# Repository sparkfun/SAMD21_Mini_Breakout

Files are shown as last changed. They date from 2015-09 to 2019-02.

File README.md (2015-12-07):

SparkFun SAMD21 Mini Breakout
========================================

SparkFun SAMD21 Mini Breakout

[*SparkFun SAMD21 Mini Breakout (DEV-13664)*](https://www.sparkfun.com/products/13664)

The SAMD21 Mini Breakout is a [Pro Mini](https://www.sparkfun.com/products/11114)-sized breakout for the Atmel [ATSAMD21G18](http://www.atmel.com/devices/ATSAMD21G18.aspx), a 32-bit ARM Cortex-M0+ processor with 256KB flash, 32KB SRAM, and an operating speed of up to 48MHz. The SAMD21 is compatible with the Arduino IDE, and libraries for the Arduino Zero.

Repository Contents
-------------------

* **/Documentation** - Data sheets, additional product information
* **/Firmware** - SAMD21 Arduino Bootloader
* **/Hardware** - Eagle design files (.brd, .sch)
* **/Production** - Production panel files (.brd)

Documentation
--------------
* **[Hookup Guide](https://learn.sparkfun.com/tutorials/samd21-minidev-breakout-hookup-guide/resources--going-further)** - Basic hookup guide for the SAMD21 Mini Breakout.

Product Versions
----------------
* [DEV-13664](https://www.sparkfun.com/products/13664) - Initial product release - v10.
* [DEV-13672](https://www.sparkfun.com/products/13672) - The SparkFun SAMD21 _Dev_ Breakout -- a similar, Arduino-shaped version of this board.

Version History
---------------
* [v1.0](https://github.com/sparkfun/SAMD21G_Mini_Breakout/tree/v10) - Initial release 

License Information
-------------------

This product is _**open source**_! 

Please review the LICENSE.md file for license information. 

If you have any questions or concerns on licensing, please contact techsupport@sparkfun.com.

Distributed as-is; no warranty is given.

- Your friends at SparkFun.

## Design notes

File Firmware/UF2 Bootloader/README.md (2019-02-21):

UF2 Bootloader for the SAMD21 Mini Breakout
==========================================
**Current Version**: UF2 Bootloader v3.2.2-1-gdec2fb7-dirty SFHWRO
**Updated**: 2/20/2019

What is UF2? It's probably best to read the documents [HERE](https://makecode.com/blog/one-chip-to-flash-them-all). The TLDR however, is that it's a bootloader that turns your micro-controller 
into a flash drive. The example bootloader provided here was created 2/20/2019
and further support is not guaranteed. However you can learn a bit about _how_
to build your own bootloader at Microsoft's [repo](https://github.com/Microsoft/uf2).
The hardest part will be ensuring that you have all the necessary build dependencies.

To update your SAMD21 Mini with the bootloader is simple. If you already have a
bootloader on it, i.e. you can see it populate in Arduino and/or Device
Manager, then all you have to do is open the "Update-Bootloader.ino" sketch and
upload it. Afterwards, you should see the SAMD21 pop up as a **SPARKFUN** drive. 
I have also included an "update" binary file for those that want to use some
GUI or command line interface instead, as well as _just_ the bootloader for
those that don't already have a bootloader installed on their micro-controller.

Circuit Python 
------------------
**Current Version**: Adafruit CircuitPython 4.0.0-beta.1-46-g3d0757102  
**Updated**: 2/20/2019

Circuit Python is Adafruit's version of Micro Python. You can read general
information about it [HERE](https://learn.adafruit.com/welcome-to-circuitpython).
They also have some documentation on how to build a version of Circuit Python
on their website [here](https://learn.adafruit.com/building-circuitpython/build-circuitpython). 
I have included a build of it under the Circuit Python folder. Assuming that
you have uploaded the UF2 bootloader above, than all you need to do is drag and
drop the UF2 file in the Circuit Python folder into your **SPARKFUN** drive and 
you're good to go! The Sparkfun drive will momentarily disappear and a **CIRCUITPY** 
drive will take its place.

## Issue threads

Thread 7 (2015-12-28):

PWM D13 led

wifixcort, 2015-12-28:
Hi, I'm currently testing this Mini board and I maybe find a strange behavior.
With your example in this page https://learn.sparkfun.com/tutorials/samd21-minidev-breakout-hookup-guide/setting-up-arduino.

When I upload the sketch  the led 13 does not fade. If I change the board from Mini to Dev board all good.

jimblom, 2016-01-21:
This is an unfortunate side effect of equipping pins 10-13 on the Mini with SPI support (compare the [Mini's pin 13 declaration](https://github.com/sparkfun/Arduino_Boards/blob/master/sparkfun/samd/variants/SparkFun_SAMD_Mini/variant.cpp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) to the [Dev/Zero's](https://github.com/sparkfun/Arduino_Boards/blob/master/sparkfun/samd/variants/arduino_zero/variant.cpp#L137)). The pin's peripheral is, at least initially, muxed to SERCOM instead of a timer.

The [pinPeripheral function](https://github.com/sparkfun/Arduino_Boards/blob/master/sparkfun/samd/cores/arduino/wiring_private.c#L22) can be used to change a pin's mux, but it's not publicly available to the Arduino sketch. Adding **`#include "wiring_private.h"`** to the top of the sketch, and throwing **`pinPeripheral(13, PIO_TIMER);`** at the start of `setup()` isn't pretty, but it works.

Thanks for the letting us know about this. I'll make a note in the tutorial.

drewfish, 2016-01-21:
Yeah, I desoldered the LED 13 from my Mini so that SPI traffic wouldn't light it up (and eat battery power).

ianccole, 2020-07-16:
I think it's not enough to re-program the port mux  - you also need to modify g_APinDescription for the specified pin.

analogWrite() uses g_APinDescription to control it's action

ianccole, 2020-07-16:
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

I think it's not enough to re-program the port mux - you also need to modify g_APinDescription for the specified pin.

analogWrite() uses g_APinDescription to control it's action

Closed 2016-01-21.

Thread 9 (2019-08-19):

Crystal 32.7khrz? specficcations 48MHz  ?

ThomasLengeling, 2019-08-19:
The schematics say that the board is using a 32.7hrz and the specifications mention that the board runs at 48Mhrz. Does the board runs with the external clock or the internal?

Thank you for your help.

spacenate, 2023-08-11:
An external 32.768 kHz crystal oscillator allows for higher accuracy (and is required for some peripherals, i.e USB in host mode).

See this excellent blog post for more details: https://blog.thea.codes/understanding-the-sam-d21-clocks/

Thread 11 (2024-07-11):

PWM D13 led, take 2

abetis, 2024-07-11:
Hi.
Take 2 for the issue #7 .

Is there a solution to use the pin13 LED on the SparkFun SAMD21 Mini board as a PWM output?
Unfortunately `pinPeripheral(13, PIO_TIMER);` doesn't help.

Looks like the `g_APinDescription` have that line cofigured as PWM capable:
```
// 13 (LED)
  { PORTA, 17, PIO_SERCOM, (PIN_ATTR_DIGITAL|PIN_ATTR_PWM), No_ADC_Channel, PWM2_CH1, NOT_ON_TIMER, EXTERNAL_INT_1 }, // TCC2/WO[1]
```

But analogWrite on that pin do not light the LED.
And it doesn't default to digitalWrite either, so I guess there is something related to timers that should toggle the pin, but can't figure out what exactly should be done to make it work.

I use Sercom2 for I2C and want to use the build-in led on pin13 as a status indication with breathing LED.

Anyone managed to make that work?

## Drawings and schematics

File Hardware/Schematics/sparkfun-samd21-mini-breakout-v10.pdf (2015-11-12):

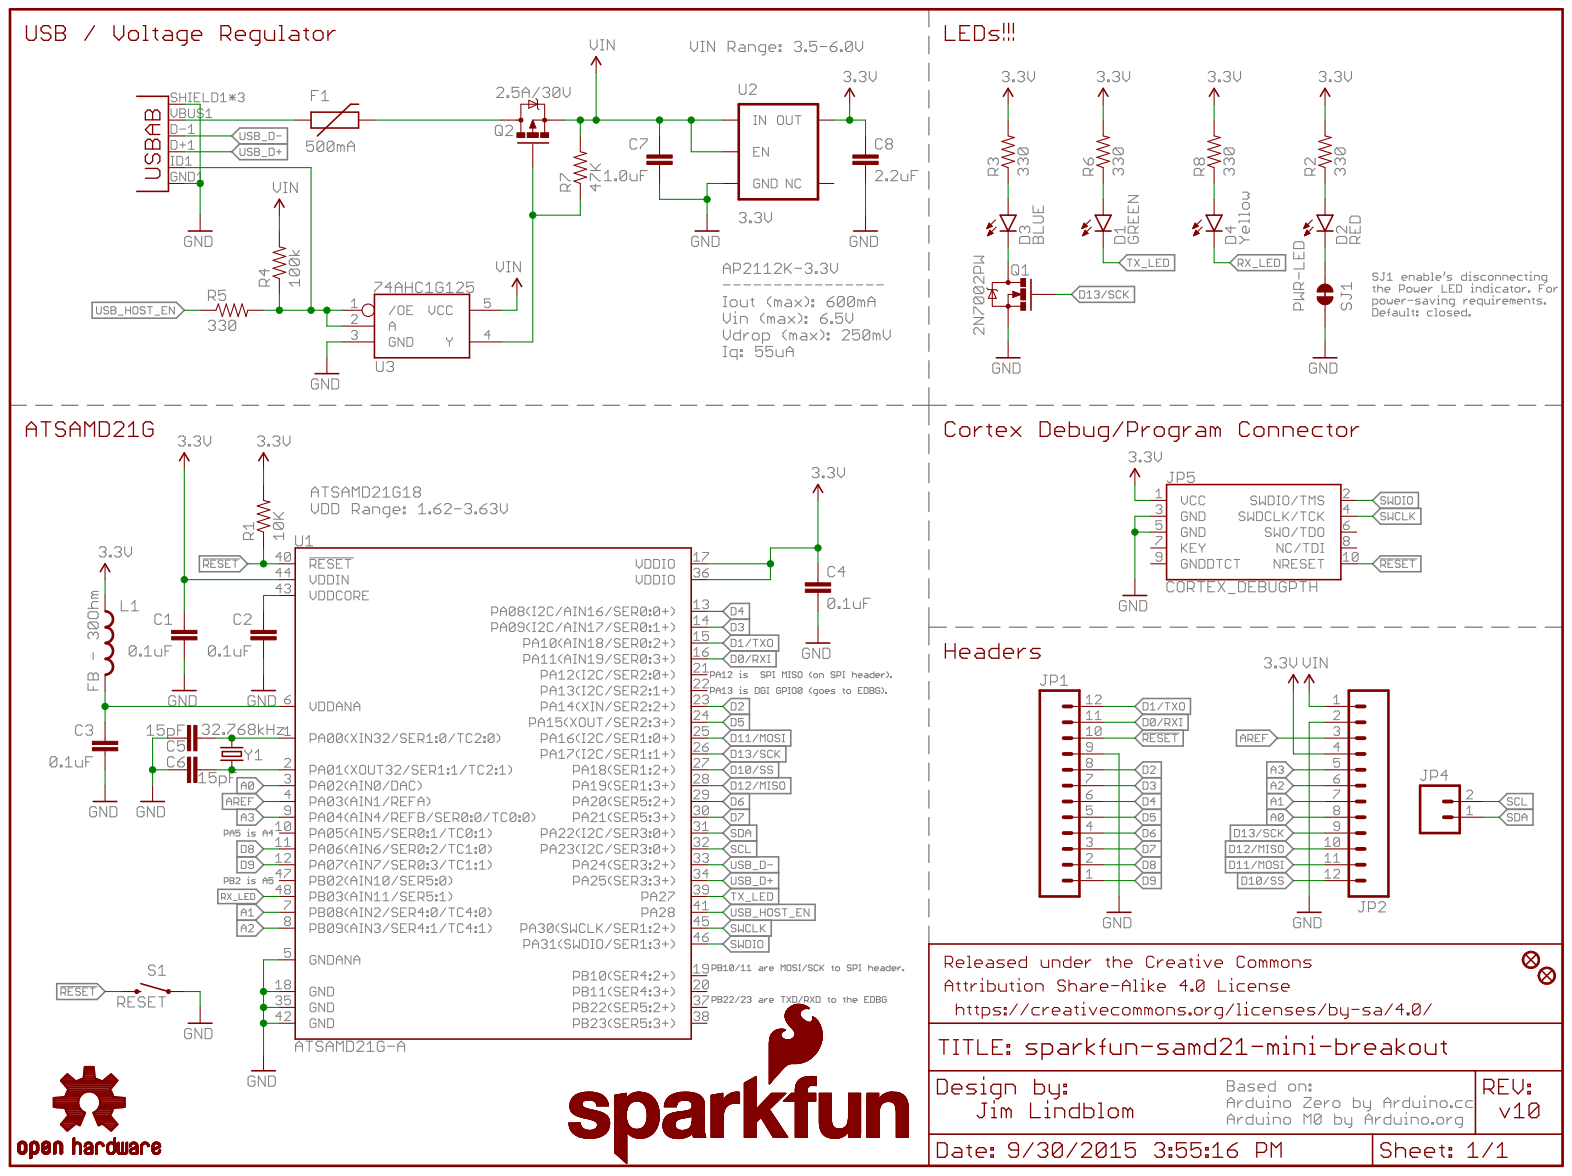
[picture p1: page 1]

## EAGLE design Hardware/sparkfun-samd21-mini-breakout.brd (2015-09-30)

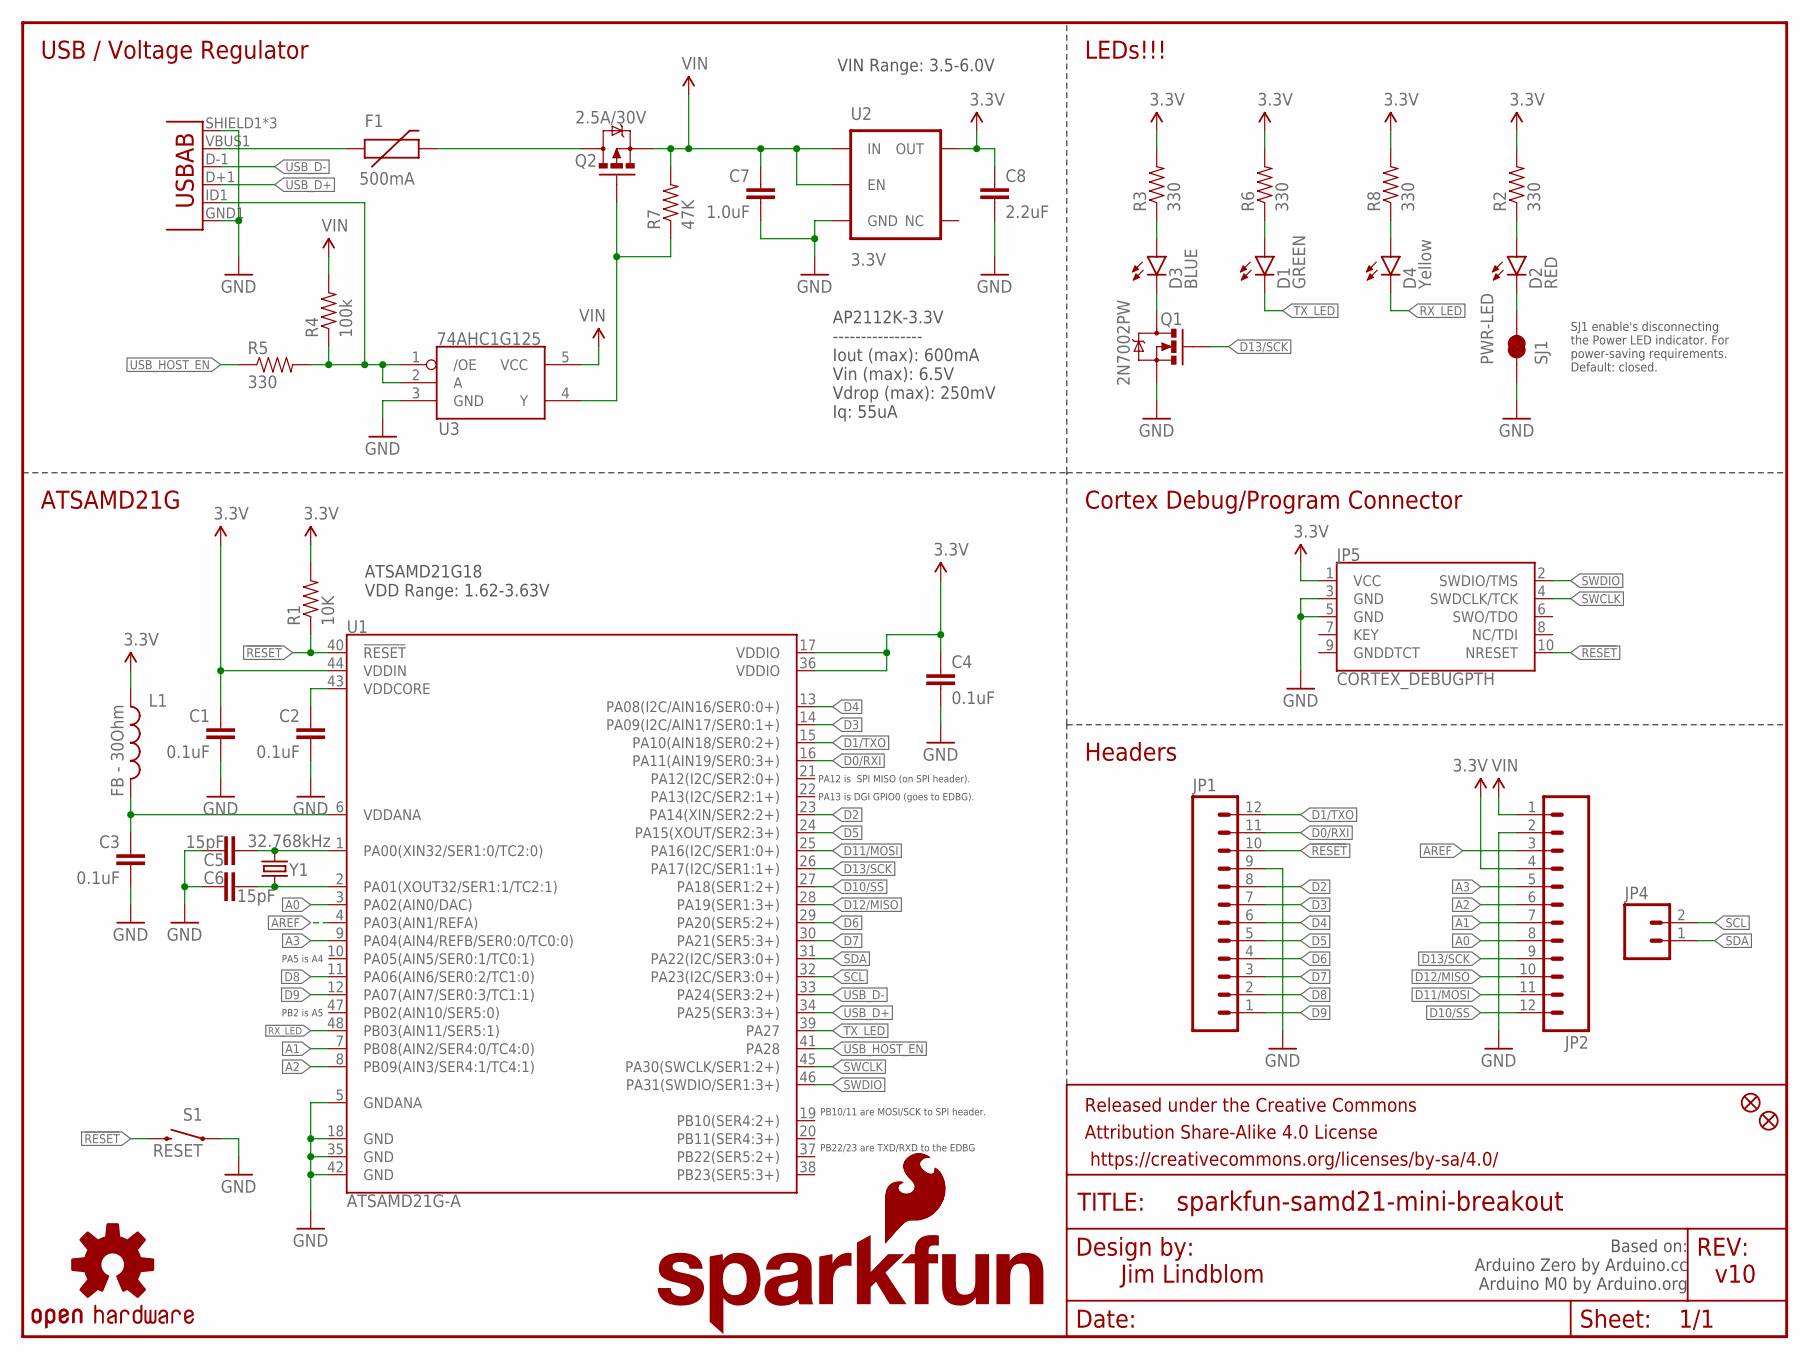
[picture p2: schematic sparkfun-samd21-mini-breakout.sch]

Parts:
C1, C2, C3, C4: 0.1uF; 0402-CAP
C5, C6: 15pF; 0402-CAP
C7: 1.0uF; 0805-CAP
C8: 2.2uF; 0603-CAP
D1: GREEN; LED-0603
D2: RED; LED-0603
D3: BLUE; LED-0603
D4: Yellow; LED-0603
F1: 500mA; PTC-1206
FID1, FID2: FIDUCIAL1X2; FIDUCIAL-1X2
FRAME1: FRAME-LETTER; CREATIVE_COMMONS
JP1, JP2: M12NO_SILK; 1X12_NO_SILK
JP3: USB-ABCONN-11794; USB-AB-MICRO-SMD_V03
JP4: M021X02_NO_SILK; 1X02_NO_SILK
JP5: CORTEX_DEBUGPTH; 2X5-PTH-1.27MM
L1: FB - 30Ohm; 0603
LOGO1: SFE_LOGO_FLAME.1_INCH; SFE_LOGO_FLAME_.1
LOGO2: OSHW-LOGOS; OSHW-LOGO-S
LOGO3: SFE_LOGO_NAME_FLAME.1_INCH; SFE_LOGO_NAME_FLAME_.1
Q1: 2N7002PW; SOT323
Q2: 2.5A/30V; SOT23-3
R1: 10K; 0603-RES
R2, R3, R5, R6, R8: 330; 0603-RES
R4: 100k; 0603-RES
R7: 47K; 0603-RES
S1: RESET; TACTILE_SWITCH_SMD_4.6X2.8MM
SJ1: PWR-LED; PAD-JUMPER-2-NC_BY_TRACE_NO_SILK
U1: ATSAMD21G-A; TQFP-48
U2: 3.3V; SOT23-5
U3: 74AHC1G125; SOT23-5
Y1: 32.768kHz; CRYSTAL-SMD-3.2X1.5MM

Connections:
3.3V: C1.1, C4.1, C8.1, JP2.4, JP5.1 (VCC), L1.1, R1.2, R2.2, R3.2, R6.2, R8.2, U1.17 (VDDIO), U1.36 (VDDIO), U1.44 (VDDIN), U2.5 (OUT)
!RESET: JP1.10, JP5.10 (NRESET), R1.1, S1.3 (2), S1.4 (2), U1.40 (!RESET!)
A0: JP2.8, U1.3 (PA02(AIN0/DAC))
A1: JP2.7, U1.7 (PB08(AIN2/SER4:0/TC4:0))
A2: JP2.6, U1.8 (PB09(AIN3/SER4:1/TC4:1))
A3: JP2.5, U1.9 (PA04(AIN4/REFB/SER0:0/TC0:0))
AREF: JP2.3, U1.4 (PA03(AIN1/REFA))
D0/RXI: JP1.11, U1.16 (PA11(AIN19/SER0:3+))
D1/TXO: JP1.12, U1.15 (PA10(AIN18/SER0:2+))
D2: JP1.8, U1.23 (PA14(XIN/SER2:2+))
D3: JP1.7, U1.14 (PA09(I2C/AIN17/SER0:1+))
D4: JP1.6, U1.13 (PA08(I2C/AIN16/SER0:0+))
D5: JP1.5, U1.24 (PA15(XOUT/SER2:3+))
D6: JP1.4, U1.29 (PA20(SER5:2+))
D7: JP1.3, U1.30 (PA21(SER5:3+))
D8: JP1.2, U1.11 (PA06(AIN6/SER0:2/TC1:0))
D9: JP1.1, U1.12 (PA07(AIN7/SER0:3/TC1:1))
D10/SS: JP2.12, U1.27 (PA18(SER1:2+))
D11/MOSI: JP2.11, U1.25 (PA16(I2C/SER1:0+))
D12/MISO: JP2.10, U1.28 (PA19(SER1:3+))
D13/SCK: JP2.9, Q1.1 (G), U1.26 (PA17(I2C/SER1:1+))
GND: C1.2, C2.2, C3.2, C4.2, C5.1, C6.2, C7.2, C8.2, JP1.9, JP2.2, JP3.GND1 (GND), JP3.SHIELD1 (SHIELD), JP3.SHIELD2 (SHIELD), JP3.SHIELD3 (SHIELD), JP5.3 (GND), JP5.5 (GND), Q1.2 (S), S1.1, S1.2 (1), SJ1.1, U1.5 (GNDANA), U1.18 (GND), U1.35 (GND), U1.42 (GND), U2.2 (GND), U3.3 (GND)
unnamed: F1.1, JP3.VBUS1 (VBUS)
unnamed: C5.2, U1.1 (PA00(XIN32/SER1:0/TC2:0)), Y1.P$2 (2)
unnamed: D3.C, Q1.3 (D)
unnamed: C6.1, U1.2 (PA01(XOUT32/SER1:1/TC2:1)), Y1.P$1 (1)
unnamed: D2.A, R2.1
unnamed: D3.A, R3.1
unnamed: F1.2, Q2.3 (D)
unnamed: JP3.ID1 (USBID), R4.1, R5.2, U3.1 (/OE), U3.2 (A)
unnamed: Q2.1 (G), R7.1, U3.4 (Y)
unnamed: D1.A, R6.1
unnamed: D4.A, R8.1
unnamed: D2.C, SJ1.2
RX_LED: D4.C, U1.48 (PB03(AIN11/SER5:1))
SCL: JP4.2, U1.32 (PA23(I2C/SER3:0+))
SDA: JP4.1, U1.31 (PA22(I2C/SER3:0+))
SWCLK: JP5.4 (SWDCLK/TCK), U1.45 (PA30(SWCLK/SER1:2+))
SWDIO: JP5.2 (SWDIO/TMS), U1.46 (PA31(SWDIO/SER1:3+))
TX_LED: D1.C, U1.39 (PA27)
USB_D+: JP3.D+1 (D+), U1.34 (PA25(SER3:3+))
USB_D-: JP3.D-1 (D-), U1.33 (PA24(SER3:2+))
USB_HOST_EN: R5.1, U1.41 (PA28)
VDDANA: C3.1, L1.2, U1.6 (VDDANA)
VDDCORE: C2.1, U1.43 (VDDCORE)
VIN: C7.1, JP2.1, Q2.2 (S), R4.2, R7.2, U2.1 (IN), U2.3 (EN), U3.5 (VCC)

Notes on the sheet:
PB22/23 are TXD/RXD to the EDBG
PB10/11 are MOSI/SCK to SPI header.
PA12 is SPI MISO (on SPI header).
PA13 is DGI GPIO0 (goes to EDBG).
PA5 is A4
PB2 is A5
USB / Voltage Regulator
LEDs!!!
Cortex Debug/Program Connector
Headers
ATSAMD21G
Jim Lindblom
v10
ATSAMD21G18 VDD Range: 1.62-3.63V
SJ1 enable's disconnecting the Power LED indicator. For power-saving requirements. Default: closed.
VIN Range: 3.5-6.0V
Based on: Arduino Zero by Arduino.cc Arduino M0 by Arduino.org
AP2112K-3.3V ---------------- Iout (max): 600mA Vin (max): 6.5V Vdrop (max): 250mV Iq: 55uA

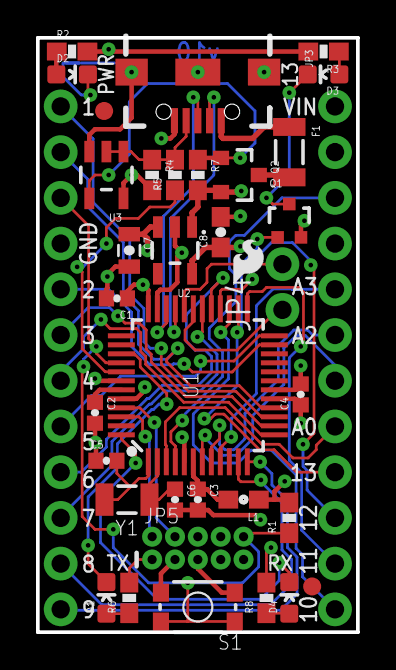
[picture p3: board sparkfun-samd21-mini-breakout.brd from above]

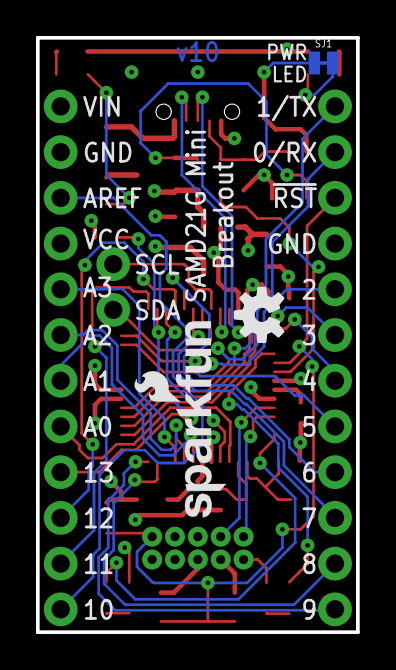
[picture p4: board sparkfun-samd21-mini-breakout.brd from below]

Board: 4 copper layers, 17.8 x 33.0 mm, 41 parts (3 on the bottom side), 46 nets.

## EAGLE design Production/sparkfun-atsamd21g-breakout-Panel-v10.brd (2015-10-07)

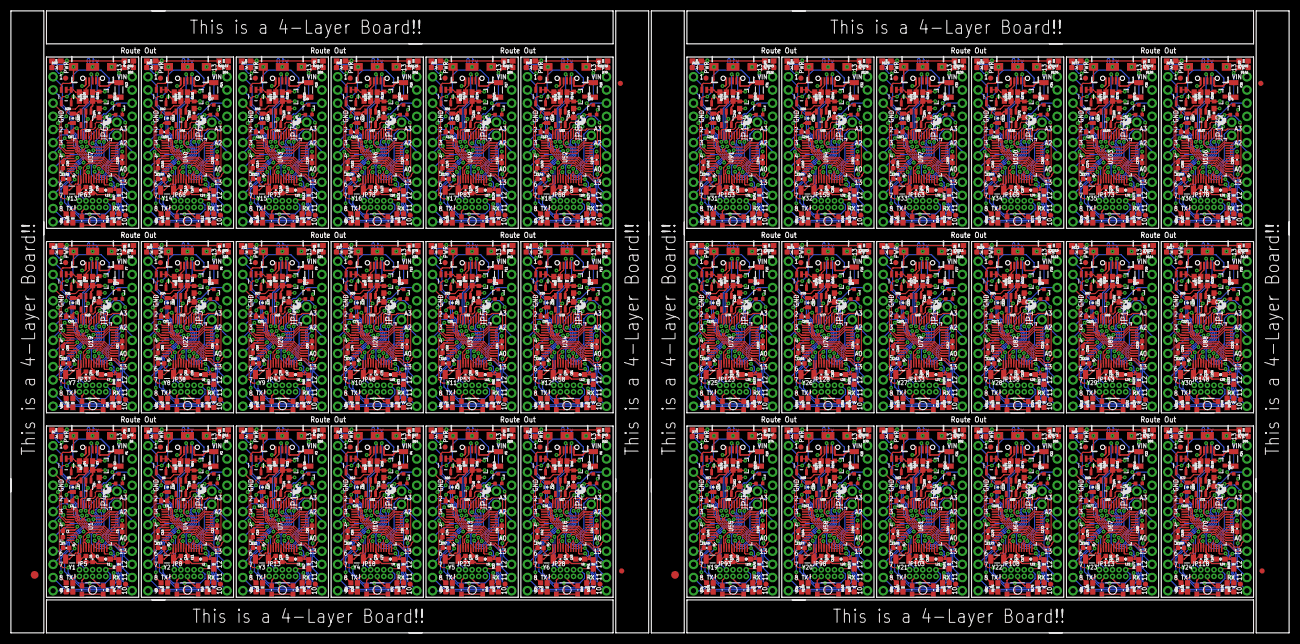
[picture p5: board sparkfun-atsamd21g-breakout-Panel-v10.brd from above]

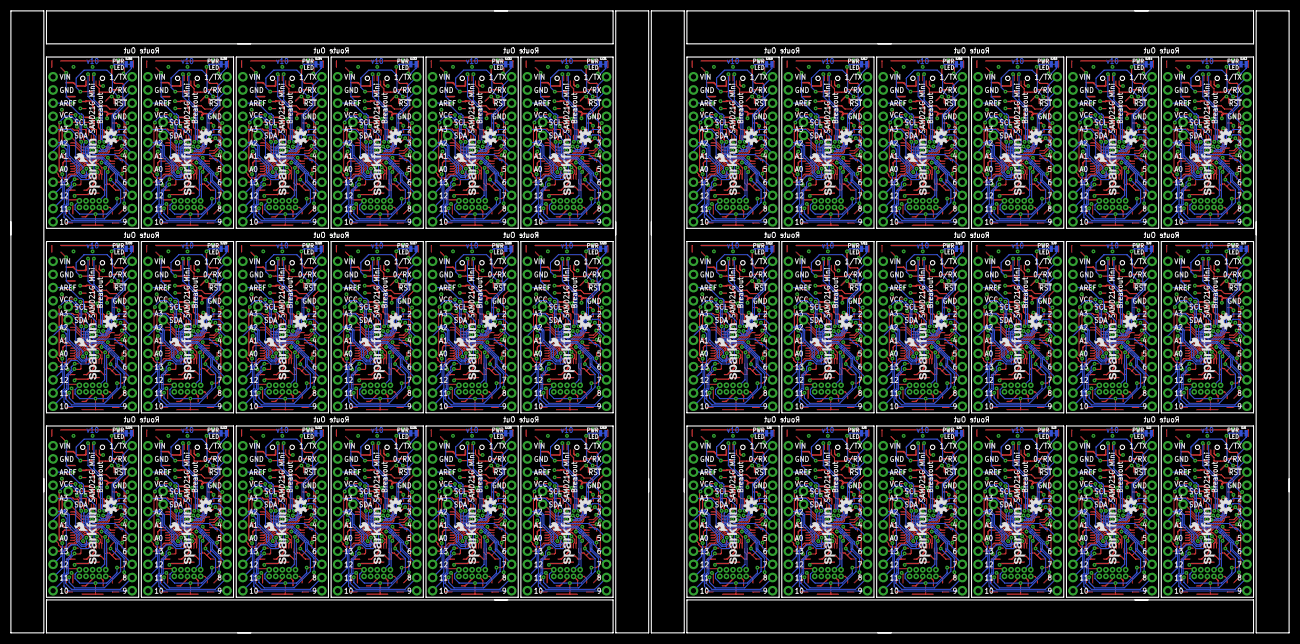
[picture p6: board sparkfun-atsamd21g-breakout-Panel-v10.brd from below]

Board: 4 copper layers, 246.4 x 119.9 mm, 1446 parts (108 on the bottom side), 1656 nets.

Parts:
C1, C2, C3, C4, C9, C10, C11, C12, C17, C18, C19, C20, C25, C26, C27, C28, C33, C34, C35, C36, C41, C42, C43, C44, C49, C50, C51, C52, C57, C58, C59, C60, C65, C66, C67, C68, C73, C74, C75, C76, C81, C82, C83, C84, C89, C90, C91, C92, C97, C98, C99, C100, C105, C106, C107, C108, C113, C114, C115, C116, C121, C122, C123, C124, C129, C130, C131, C132, C137, C138, C139, C140, C145, C146, C147, C148, C153, C154, C155, C156, C161, C162, C163, C164, C169, C170, C171, C172, C177, C178, C179, C180, C185, C186, C187, C188, C193, C194, C195, C196, C201, C202, C203, C204, C209, C210, C211, C212, C217, C218, C219, C220, C225, C226, C227, C228, C233, C234, C235, C236, C241, C242, C243, C244, C249, C250, C251, C252, C257, C258, C259, C260, C265, C266, C267, C268, C273, C274, C275, C276, C281, C282, C283, C284: 0.1uF; 0402-CAP
C5, C6, C13, C14, C21, C22, C29, C30, C37, C38, C45, C46, C53, C54, C61, C62, C69, C70, C77, C78, C85, C86, C93, C94, C101, C102, C109, C110, C117, C118, C125, C126, C133, C134, C141, C142, C149, C150, C157, C158, C165, C166, C173, C174, C181, C182, C189, C190, C197, C198, C205, C206, C213, C214, C221, C222, C229, C230, C237, C238, C245, C246, C253, C254, C261, C262, C269, C270, C277, C278, C285, C286: 15pF; 0402-CAP
C7, C15, C23, C31, C39, C47, C55, C63, C71, C79, C87, C95, C103, C111, C119, C127, C135, C143, C151, C159, C167, C175, C183, C191, C199, C207, C215, C223, C231, C239, C247, C255, C263, C271, C279, C287: 1.0uF; 0805-CAP
C8, C16, C24, C32, C40, C48, C56, C64, C72, C80, C88, C96, C104, C112, C120, C128, C136, C144, C152, C160, C168, C176, C184, C192, C200, C208, C216, C224, C232, C240, C248, C256, C264, C272, C280, C288: 2.2uF; 0603-CAP
D1, D7, D11, D15, D19, D23, D27, D31, D35, D39, D43, D47, D51, D55, D59, D63, D67, D71, D75, D79, D83, D87, D91, D95, D99, D103, D107, D111, D115, D119, D123, D127, D131, D135, D139, D143: GREEN; LED-0603
D2, D5, D9, D13, D17, D21, D25, D29, D33, D37, D41, D45, D49, D53, D57, D61, D65, D69, D73, D77, D81, D85, D89, D93, D97, D101, D105, D109, D113, D117, D121, D125, D129, D133, D137, D141: RED; LED-0603
D3, D6, D10, D14, D18, D22, D26, D30, D34, D38, D42, D46, D50, D54, D58, D62, D66, D70, D74, D78, D82, D86, D90, D94, D98, D102, D106, D110, D114, D118, D122, D126, D130, D134, D138, D142: BLUE; LED-0603
D4, D8, D12, D16, D20, D24, D28, D32, D36, D40, D44, D48, D52, D56, D60, D64, D68, D72, D76, D80, D84, D88, D92, D96, D100, D104, D108, D112, D116, D120, D124, D128, D132, D136, D140, D144: Yellow; LED-0603
E$1, E$4: FIDUCIAL-1.5X3
E$2, E$3, E$5, E$6: FIDUCIAL-1X2
F1, F2, F3, F4, F5, F6, F7, F8, F9, F10, F11, F12, F13, F14, F15, F16, F17, F18, F19, F20, F21, F22, F23, F24, F25, F26, F27, F28, F29, F30, F31, F32, F33, F34, F35, F36: 500mA; PTC-1206
FID1, FID2, FID3, FID4, FID5, FID6, FID7, FID8, FID9, FID10, FID11, FID12, FID13, FID14, FID15, FID16, FID17, FID18, FID19, FID20, FID21, FID22, FID23, FID24, FID25, FID26, FID27, FID28, FID29, FID30, FID31, FID32, FID33, FID34, FID35, FID36, FID37, FID38, FID39, FID40, FID41, FID42, FID43, FID44, FID45, FID46, FID47, FID48, FID49, FID50, FID51, FID52, FID53, FID54, FID55, FID56, FID57, FID58, FID59, FID60, FID61, FID62, FID63, FID64, FID65, FID66, FID67, FID68, FID69, FID70, FID71, FID72: FIDUCIAL1X2; FIDUCIAL-1X2
JP1, JP2, JP6, JP7, JP11, JP12, JP16, JP17, JP21, JP22, JP26, JP27, JP31, JP32, JP36, JP37, JP41, JP42, JP46, JP47, JP51, JP52, JP56, JP57, JP61, JP62, JP66, JP67, JP71, JP72, JP76, JP77, JP81, JP82, JP86, JP87, JP91, JP92, JP96, JP97, JP101, JP102, JP106, JP107, JP111, JP112, JP116, JP117, JP121, JP122, JP126, JP127, JP131, JP132, JP136, JP137, JP141, JP142, JP146, JP147, JP151, JP152, JP156, JP157, JP161, JP162, JP166, JP167, JP171, JP172, JP176, JP177: 1X12_NO_SILK
JP3, JP10, JP15, JP20, JP25, JP30, JP35, JP40, JP45, JP50, JP55, JP60, JP65, JP70, JP75, JP80, JP85, JP90, JP95, JP100, JP105, JP110, JP115, JP120, JP125, JP130, JP135, JP140, JP145, JP150, JP155, JP160, JP165, JP170, JP175, JP180: USB-AB-MICRO-SMD_V03
JP4, JP9, JP14, JP19, JP24, JP29, JP34, JP39, JP44, JP49, JP54, JP59, JP64, JP69, JP74, JP79, JP84, JP89, JP94, JP99, JP104, JP109, JP114, JP119, JP124, JP129, JP134, JP139, JP144, JP149, JP154, JP159, JP164, JP169, JP174, JP179: 1X02_NO_SILK
JP5, JP8, JP13, JP18, JP23, JP28, JP33, JP38, JP43, JP48, JP53, JP58, JP63, JP68, JP73, JP78, JP83, JP88, JP93, JP98, JP103, JP108, JP113, JP118, JP123, JP128, JP133, JP138, JP143, JP148, JP153, JP158, JP163, JP168, JP173, JP178: CORTEX_DEBUGPTH; 2X5-PTH-1.27MM
L1, L2, L3, L4, L5, L6, L7, L8, L9, L10, L11, L12, L13, L14, L15, L16, L17, L18, L19, L20, L21, L22, L23, L24, L25, L26, L27, L28, L29, L30, L31, L32, L33, L34, L35, L36: FB - 30Ohm; 0603
LOGO1, LOGO4, LOGO7, LOGO10, LOGO13, LOGO16, LOGO19, LOGO22, LOGO25, LOGO28, LOGO31, LOGO34, LOGO37, LOGO40, LOGO43, LOGO46, LOGO49, LOGO52, LOGO55, LOGO58, LOGO61, LOGO64, LOGO67, LOGO70, LOGO73, LOGO76, LOGO79, LOGO82, LOGO85, LOGO88, LOGO91, LOGO94, LOGO97, LOGO100, LOGO103, LOGO106: SFE_LOGO_FLAME.1_INCH; SFE_LOGO_FLAME_.1
LOGO2, LOGO5, LOGO8, LOGO11, LOGO14, LOGO17, LOGO20, LOGO23, LOGO26, LOGO29, LOGO32, LOGO35, LOGO38, LOGO41, LOGO44, LOGO47, LOGO50, LOGO53, LOGO56, LOGO59, LOGO62, LOGO65, LOGO68, LOGO71, LOGO74, LOGO77, LOGO80, LOGO83, LOGO86, LOGO89, LOGO92, LOGO95, LOGO98, LOGO101, LOGO104, LOGO107: OSHW-LOGOS; OSHW-LOGO-S
LOGO3, LOGO6, LOGO9, LOGO12, LOGO15, LOGO18, LOGO21, LOGO24, LOGO27, LOGO30, LOGO33, LOGO36, LOGO39, LOGO42, LOGO45, LOGO48, LOGO51, LOGO54, LOGO57, LOGO60, LOGO63, LOGO66, LOGO69, LOGO72, LOGO75, LOGO78, LOGO81, LOGO84, LOGO87, LOGO90, LOGO93, LOGO96, LOGO99, LOGO102, LOGO105, LOGO108: SFE_LOGO_NAME_FLAME.1_INCH; SFE_LOGO_NAME_FLAME_.1
Q1, Q3, Q5, Q7, Q9, Q11, Q13, Q15, Q17, Q19, Q21, Q23, Q25, Q27, Q29, Q31, Q33, Q35, Q37, Q39, Q41, Q43, Q45, Q47, Q49, Q51, Q53, Q55, Q57, Q59, Q61, Q63, Q65, Q67, Q69, Q71: 2N7002PW; SOT323
Q2, Q4, Q6, Q8, Q10, Q12, Q14, Q16, Q18, Q20, Q22, Q24, Q26, Q28, Q30, Q32, Q34, Q36, Q38, Q40, Q42, Q44, Q46, Q48, Q50, Q52, Q54, Q56, Q58, Q60, Q62, Q64, Q66, Q68, Q70, Q72: 2.5A/30V; SOT23-3
R1, R9, R17, R25, R33, R41, R49, R57, R65, R73, R81, R89, R97, R105, R113, R121, R129, R137, R145, R153, R161, R169, R177, R185, R193, R201, R209, R217, R225, R233, R241, R249, R257, R265, R273, R281: 10K; 0603-RES
R2, R3, R5, R6, R8, R10, R11, R13, R15, R16, R18, R19, R21, R23, R24, R26, R27, R29, R31, R32, R34, R35, R37, R39, R40, R42, R43, R45, R47, R48, R50, R51, R53, R55, R56, R58, R59, R61, R63, R64, R66, R67, R69, R71, R72, R74, R75, R77, R79, R80, R82, R83, R85, R87, R88, R90, R91, R93, R95, R96, R98, R99, R101, R103, R104, R106, R107, R109, R111, R112, R114, R115, R117, R119, R120, R122, R123, R125, R127, R128, R130, R131, R133, R135, R136, R138, R139, R141, R143, R144, R146, R147, R149, R151, R152, R154, R155, R157, R159, R160, R162, R163, R165, R167, R168, R170, R171, R173, R175, R176, R178, R179, R181, R183, R184, R186, R187, R189, R191, R192, R194, R195, R197, R199, R200, R202, R203, R205, R207, R208, R210, R211, R213, R215, R216, R218, R219, R221, R223, R224, R226, R227, R229, R231, R232, R234, R235, R237, R239, R240, R242, R243, R245, R247, R248, R250, R251, R253, R255, R256, R258, R259, R261, R263, R264, R266, R267, R269, R271, R272, R274, R275, R277, R279, R280, R282, R283, R285, R287, R288: 330; 0603-RES
R4, R12, R20, R28, R36, R44, R52, R60, R68, R76, R84, R92, R100, R108, R116, R124, R132, R140, R148, R156, R164, R172, R180, R188, R196, R204, R212, R220, R228, R236, R244, R252, R260, R268, R276, R284: 100k; 0603-RES
R7, R14, R22, R30, R38, R46, R54, R62, R70, R78, R86, R94, R102, R110, R118, R126, R134, R142, R150, R158, R166, R174, R182, R190, R198, R206, R214, R222, R230, R238, R246, R254, R262, R270, R278, R286: 47K; 0603-RES
S1, S2, S3, S4, S5, S6, S7, S8, S9, S10, S11, S12, S13, S14, S15, S16, S17, S18, S19, S20, S21, S22, S23, S24, S25, S26, S27, S28, S29, S30, S31, S32, S33, S34, S35, S36: RESET; TACTILE_SWITCH_SMD_4.6X2.8MM
SJ1, SJ2, SJ3, SJ4, SJ5, SJ6, SJ7, SJ8, SJ9, SJ10, SJ11, SJ12, SJ13, SJ14, SJ15, SJ16, SJ17, SJ18, SJ19, SJ20, SJ21, SJ22, SJ23, SJ24, SJ25, SJ26, SJ27, SJ28, SJ29, SJ30, SJ31, SJ32, SJ33, SJ34, SJ35, SJ36: PWR-LED; PAD-JUMPER-2-NC_BY_TRACE_NO_SILK
U1, U4, U7, U10, U13, U16, U19, U22, U25, U28, U31, U34, U37, U40, U43, U46, U49, U52, U55, U58, U61, U64, U67, U70, U73, U76, U79, U82, U85, U88, U91, U94, U97, U100, U103, U106: ATSAMD21G-A; TQFP-48
U2, U5, U8, U11, U14, U17, U20, U23, U26, U29, U32, U35, U38, U41, U44, U47, U50, U53, U56, U59, U62, U65, U68, U71, U74, U77, U80, U83, U86, U89, U92, U95, U98, U101, U104, U107: 3.3V; SOT23-5
U3, U6, U9, U12, U15, U18, U21, U24, U27, U30, U33, U36, U39, U42, U45, U48, U51, U54, U57, U60, U63, U66, U69, U72, U75, U78, U81, U84, U87, U90, U93, U96, U99, U102, U105, U108: 74AHC1G125; SOT23-5
Y1, Y2, Y3, Y4, Y5, Y6, Y7, Y8, Y9, Y10, Y11, Y12, Y13, Y14, Y15, Y16, Y17, Y18, Y19, Y20, Y21, Y22, Y23, Y24, Y25, Y26, Y27, Y28, Y29, Y30, Y31, Y32, Y33, Y34, Y35, Y36: 32.768kHz; CRYSTAL-SMD-3.2X1.5MM

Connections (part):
3.3V: C1.1, C4.1, C8.1, JP2.4, JP5.1, L1.1, R1.2, R2.2, R3.2, R6.2, R8.2, U1.17, U1.36, U1.44, U2.5
3.3V1: C9.1, C12.1, C16.1, JP7.4, JP8.1, L2.1, R9.2, R10.2, R11.2, R15.2, R16.2, U4.17, U4.36, U4.44, U5.5
3.3V2: C17.1, C20.1, C24.1, JP12.4, JP13.1, L3.1, R17.2, R18.2, R19.2, R23.2, R24.2, U7.17, U7.36, U7.44, U8.5
3.3V3: C25.1, C28.1, C32.1, JP17.4, JP18.1, L4.1, R25.2, R26.2, R27.2, R31.2, R32.2, U10.17, U10.36, U10.44, U11.5
3.3V4: C33.1, C36.1, C40.1, JP22.4, JP23.1, L5.1, R33.2, R34.2, R35.2, R39.2, R40.2, U13.17, U13.36, U13.44, U14.5
3.3V5: C41.1, C44.1, C48.1, JP27.4, JP28.1, L6.1, R41.2, R42.2, R43.2, R47.2, R48.2, U16.17, U16.36, U16.44, U17.5
3.3V6: C49.1, C52.1, C56.1, JP32.4, JP33.1, L7.1, R49.2, R50.2, R51.2, R55.2, R56.2, U19.17, U19.36, U19.44, U20.5
3.3V7: C57.1, C60.1, C64.1, JP37.4, JP38.1, L8.1, R57.2, R58.2, R59.2, R63.2, R64.2, U22.17, U22.36, U22.44, U23.5
3.3V8: C65.1, C68.1, C72.1, JP42.4, JP43.1, L9.1, R65.2, R66.2, R67.2, R71.2, R72.2, U25.17, U25.36, U25.44, U26.5
3.3V9: C73.1, C76.1, C80.1, JP47.4, JP48.1, L10.1, R73.2, R74.2, R75.2, R79.2, R80.2, U28.17, U28.36, U28.44, U29.5
3.3V10: C81.1, C84.1, C88.1, JP52.4, JP53.1, L11.1, R81.2, R82.2, R83.2, R87.2, R88.2, U31.17, U31.36, U31.44, U32.5
3.3V11: C89.1, C92.1, C96.1, JP57.4, JP58.1, L12.1, R89.2, R90.2, R91.2, R95.2, R96.2, U34.17, U34.36, U34.44, U35.5
3.3V12: C97.1, C100.1, C104.1, JP62.4, JP63.1, L13.1, R97.2, R98.2, R99.2, R103.2, R104.2, U37.17, U37.36, U37.44, U38.5
3.3V13: C105.1, C108.1, C112.1, JP67.4, JP68.1, L14.1, R105.2, R106.2, R107.2, R111.2, R112.2, U40.17, U40.36, U40.44, U41.5
3.3V14: C113.1, C116.1, C120.1, JP72.4, JP73.1, L15.1, R113.2, R114.2, R115.2, R119.2, R120.2, U43.17, U43.36, U43.44, U44.5
3.3V15: C121.1, C124.1, C128.1, JP77.4, JP78.1, L16.1, R121.2, R122.2, R123.2, R127.2, R128.2, U46.17, U46.36, U46.44, U47.5
3.3V16: C129.1, C132.1, C136.1, JP82.4, JP83.1, L17.1, R129.2, R130.2, R131.2, R135.2, R136.2, U49.17, U49.36, U49.44, U50.5
3.3V17: C137.1, C140.1, C144.1, JP87.4, JP88.1, L18.1, R137.2, R138.2, R139.2, R143.2, R144.2, U52.17, U52.36, U52.44, U53.5
3.3V18: C145.1, C148.1, C152.1, JP92.4, JP93.1, L19.1, R145.2, R146.2, R147.2, R151.2, R152.2, U55.17, U55.36, U55.44, U56.5
3.3V19: C153.1, C156.1, C160.1, JP97.4, JP98.1, L20.1, R153.2, R154.2, R155.2, R159.2, R160.2, U58.17, U58.36, U58.44, U59.5
3.3V20: C161.1, C164.1, C168.1, JP102.4, JP103.1, L21.1, R161.2, R162.2, R163.2, R167.2, R168.2, U61.17, U61.36, U61.44, U62.5
3.3V21: C169.1, C172.1, C176.1, JP107.4, JP108.1, L22.1, R169.2, R170.2, R171.2, R175.2, R176.2, U64.17, U64.36, U64.44, U65.5
3.3V22: C177.1, C180.1, C184.1, JP112.4, JP113.1, L23.1, R177.2, R178.2, R179.2, R183.2, R184.2, U67.17, U67.36, U67.44, U68.5
3.3V23: C185.1, C188.1, C192.1, JP117.4, JP118.1, L24.1, R185.2, R186.2, R187.2, R191.2, R192.2, U70.17, U70.36, U70.44, U71.5
3.3V24: C193.1, C196.1, C200.1, JP122.4, JP123.1, L25.1, R193.2, R194.2, R195.2, R199.2, R200.2, U73.17, U73.36, U73.44, U74.5
3.3V25: C201.1, C204.1, C208.1, JP127.4, JP128.1, L26.1, R201.2, R202.2, R203.2, R207.2, R208.2, U76.17, U76.36, U76.44, U77.5
3.3V26: C209.1, C212.1, C216.1, JP132.4, JP133.1, L27.1, R209.2, R210.2, R211.2, R215.2, R216.2, U79.17, U79.36, U79.44, U80.5
3.3V27: C217.1, C220.1, C224.1, JP137.4, JP138.1, L28.1, R217.2, R218.2, R219.2, R223.2, R224.2, U82.17, U82.36, U82.44, U83.5
3.3V28: C225.1, C228.1, C232.1, JP142.4, JP143.1, L29.1, R225.2, R226.2, R227.2, R231.2, R232.2, U85.17, U85.36, U85.44, U86.5
3.3V29: C233.1, C236.1, C240.1, JP147.4, JP148.1, L30.1, R233.2, R234.2, R235.2, R239.2, R240.2, U88.17, U88.36, U88.44, U89.5
3.3V30: C241.1, C244.1, C248.1, JP152.4, JP153.1, L31.1, R241.2, R242.2, R243.2, R247.2, R248.2, U91.17, U91.36, U91.44, U92.5
3.3V31: C249.1, C252.1, C256.1, JP157.4, JP158.1, L32.1, R249.2, R250.2, R251.2, R255.2, R256.2, U94.17, U94.36, U94.44, U95.5
3.3V32: C257.1, C260.1, C264.1, JP162.4, JP163.1, L33.1, R257.2, R258.2, R259.2, R263.2, R264.2, U97.17, U97.36, U97.44, U98.5
3.3V33: C265.1, C268.1, C272.1, JP167.4, JP168.1, L34.1, R265.2, R266.2, R267.2, R271.2, R272.2, U100.17, U100.36, U100.44, U101.5
3.3V34: C273.1, C276.1, C280.1, JP172.4, JP173.1, L35.1, R273.2, R274.2, R275.2, R279.2, R280.2, U103.17, U103.36, U103.44, U104.5
3.3V35: C281.1, C284.1, C288.1, JP177.4, JP178.1, L36.1, R281.2, R282.2, R283.2, R287.2, R288.2, U106.17, U106.36, U106.44, U107.5
!RESET: JP1.10, JP5.10, R1.1, S1.3, S1.4, U1.40
!RESET1: JP6.10, JP8.10, R9.1, S2.3, S2.4, U4.40
!RESET2: JP11.10, JP13.10, R17.1, S3.3, S3.4, U7.40
!RESET3: JP16.10, JP18.10, R25.1, S4.3, S4.4, U10.40
!RESET4: JP21.10, JP23.10, R33.1, S5.3, S5.4, U13.40
!RESET5: JP26.10, JP28.10, R41.1, S6.3, S6.4, U16.40
!RESET6: JP31.10, JP33.10, R49.1, S7.3, S7.4, U19.40
!RESET7: JP36.10, JP38.10, R57.1, S8.3, S8.4, U22.40
!RESET8: JP41.10, JP43.10, R65.1, S9.3, S9.4, U25.40
!RESET9: JP46.10, JP48.10, R73.1, S10.3, S10.4, U28.40
!RESET10: JP51.10, JP53.10, R81.1, S11.3, S11.4, U31.40
!RESET11: JP56.10, JP58.10, R89.1, S12.3, S12.4, U34.40
!RESET12: JP61.10, JP63.10, R97.1, S13.3, S13.4, U37.40
!RESET13: JP66.10, JP68.10, R105.1, S14.3, S14.4, U40.40
!RESET14: JP71.10, JP73.10, R113.1, S15.3, S15.4, U43.40
!RESET15: JP76.10, JP78.10, R121.1, S16.3, S16.4, U46.40
!RESET16: JP81.10, JP83.10, R129.1, S17.3, S17.4, U49.40
!RESET17: JP86.10, JP88.10, R137.1, S18.3, S18.4, U52.40
!RESET18: JP91.10, JP93.10, R145.1, S19.3, S19.4, U55.40
!RESET19: JP96.10, JP98.10, R153.1, S20.3, S20.4, U58.40
!RESET20: JP101.10, JP103.10, R161.1, S21.3, S21.4, U61.40
!RESET21: JP106.10, JP108.10, R169.1, S22.3, S22.4, U64.40
!RESET22: JP111.10, JP113.10, R177.1, S23.3, S23.4, U67.40
!RESET23: JP116.10, JP118.10, R185.1, S24.3, S24.4, U70.40
!RESET24: JP121.10, JP123.10, R193.1, S25.3, S25.4, U73.40
!RESET25: JP126.10, JP128.10, R201.1, S26.3, S26.4, U76.40
!RESET26: JP131.10, JP133.10, R209.1, S27.3, S27.4, U79.40
!RESET27: JP136.10, JP138.10, R217.1, S28.3, S28.4, U82.40
!RESET28: JP141.10, JP143.10, R225.1, S29.3, S29.4, U85.40
!RESET29: JP146.10, JP148.10, R233.1, S30.3, S30.4, U88.40
!RESET30: JP151.10, JP153.10, R241.1, S31.3, S31.4, U91.40
!RESET31: JP156.10, JP158.10, R249.1, S32.3, S32.4, U94.40
!RESET32: JP161.10, JP163.10, R257.1, S33.3, S33.4, U97.40
!RESET33: JP166.10, JP168.10, R265.1, S34.3, S34.4, U100.40
!RESET34: JP171.10, JP173.10, R273.1, S35.3, S35.4, U103.40
!RESET35: JP176.10, JP178.10, R281.1, S36.3, S36.4, U106.40
A0: JP2.8, U1.3
A1: JP2.7, U1.7
A2: JP2.6, U1.8
A3: JP2.5, U1.9
A4: JP7.5, U4.9
A5: JP7.6, U4.8
A6: JP7.7, U4.7
A7: JP7.8, U4.3
A8: JP12.5, U7.9
A9: JP12.6, U7.8
A10: JP12.7, U7.7
A11: JP12.8, U7.3
A12: JP17.5, U10.9
A13: JP17.6, U10.8
A14: JP17.7, U10.7
A15: JP17.8, U10.3
A16: JP22.5, U13.9
A17: JP22.6, U13.8
A18: JP22.7, U13.7
A19: JP22.8, U13.3
A20: JP27.5, U16.9
A21: JP27.6, U16.8
A22: JP27.7, U16.7
A23: JP27.8, U16.3
A24: JP32.5, U19.9
A25: JP32.6, U19.8
A26: JP32.7, U19.7
A27: JP32.8, U19.3
A28: JP37.5, U22.9
A29: JP37.6, U22.8
A30: JP37.7, U22.7
A31: JP37.8, U22.3
A32: JP42.5, U25.9
A33: JP42.6, U25.8
A34: JP42.7, U25.7
A35: JP42.8, U25.3
A36: JP47.5, U28.9
A37: JP47.6, U28.8
A38: JP47.7, U28.7
A39: JP47.8, U28.3
A40: JP52.5, U31.9
A41: JP52.6, U31.8
A42: JP52.7, U31.7
A43: JP52.8, U31.3
A44: JP57.5, U34.9
A45: JP57.6, U34.8
A46: JP57.7, U34.7
A47: JP57.8, U34.3
A48: JP62.5, U37.9
A49: JP62.6, U37.8
A50: JP62.7, U37.7
A51: JP62.8, U37.3
A52: JP67.5, U40.9
A53: JP67.6, U40.8
A54: JP67.7, U40.7
A55: JP67.8, U40.3
A56: JP72.5, U43.9
A57: JP72.6, U43.8
A58: JP72.7, U43.7
A59: JP72.8, U43.3
A60: JP77.5, U46.9
A61: JP77.6, U46.8
A62: JP77.7, U46.7
A63: JP77.8, U46.3
A64: JP82.5, U49.9
A65: JP82.6, U49.8
A66: JP82.7, U49.7
A67: JP82.8, U49.3
A68: JP87.5, U52.9
A69: JP87.6, U52.8
A70: JP87.7, U52.7
A71: JP87.8, U52.3
A72: JP92.5, U55.9
A73: JP92.6, U55.8
A74: JP92.7, U55.7
A75: JP92.8, U55.3
A76: JP97.5, U58.9
A77: JP97.6, U58.8
A78: JP97.7, U58.7
A79: JP97.8, U58.3
A80: JP102.5, U61.9
A81: JP102.6, U61.8
A82: JP102.7, U61.7
A83: JP102.8, U61.3
A84: JP107.5, U64.9
A85: JP107.6, U64.8
A86: JP107.7, U64.7
A87: JP107.8, U64.3
A88: JP112.5, U67.9
A89: JP112.6, U67.8
A90: JP112.7, U67.7
A91: JP112.8, U67.3
A92: JP117.5, U70.9
A93: JP117.6, U70.8
A94: JP117.7, U70.7
A95: JP117.8, U70.3
A96: JP122.5, U73.9
A97: JP122.6, U73.8
A98: JP122.7, U73.7
A99: JP122.8, U73.3
A100: JP127.5, U76.9
A101: JP127.6, U76.8
A102: JP127.7, U76.7
A103: JP127.8, U76.3
A104: JP132.5, U79.9
A105: JP132.6, U79.8
A106: JP132.7, U79.7
A107: JP132.8, U79.3
A108: JP137.5, U82.9
A109: JP137.6, U82.8
A110: JP137.7, U82.7
A111: JP137.8, U82.3
A112: JP142.5, U85.9
A113: JP142.6, U85.8
A114: JP142.7, U85.7
A115: JP142.8, U85.3
A116: JP147.5, U88.9
A117: JP147.6, U88.8
A118: JP147.7, U88.7
A119: JP147.8, U88.3
A120: JP152.5, U91.9
A121: JP152.6, U91.8
A122: JP152.7, U91.7
A123: JP152.8, U91.3
A124: JP157.5, U94.9
A125: JP157.6, U94.8
A126: JP157.7, U94.7
A127: JP157.8, U94.3
A128: JP162.5, U97.9
A129: JP162.6, U97.8
A130: JP162.7, U97.7
A131: JP162.8, U97.3
A132: JP167.5, U100.9
A133: JP167.6, U100.8
A134: JP167.7, U100.7
A135: JP167.8, U100.3
A136: JP172.5, U103.9
A137: JP172.6, U103.8
A138: JP172.7, U103.7
A139: JP172.8, U103.3
A140: JP177.5, U106.9
A141: JP177.6, U106.8
A142: JP177.7, U106.7
A143: JP177.8, U106.3
AREF: JP2.3, U1.4
AREF1: JP7.3, U4.4
AREF2: JP12.3, U7.4
AREF3: JP17.3, U10.4
AREF4: JP22.3, U13.4
AREF5: JP27.3, U16.4
AREF6: JP32.3, U19.4
AREF7: JP37.3, U22.4
AREF8: JP42.3, U25.4
AREF9: JP47.3, U28.4
AREF10: JP52.3, U31.4
AREF11: JP57.3, U34.4
AREF12: JP62.3, U37.4
AREF13: JP67.3, U40.4
AREF14: JP72.3, U43.4
AREF15: JP77.3, U46.4
AREF16: JP82.3, U49.4
AREF17: JP87.3, U52.4
AREF18: JP92.3, U55.4
AREF19: JP97.3, U58.4
AREF20: JP102.3, U61.4
AREF21: JP107.3, U64.4
AREF22: JP112.3, U67.4
AREF23: JP117.3, U70.4
AREF24: JP122.3, U73.4
AREF25: JP127.3, U76.4
AREF26: JP132.3, U79.4
AREF27: JP137.3, U82.4
AREF28: JP142.3, U85.4
AREF29: JP147.3, U88.4
AREF30: JP152.3, U91.4
AREF31: JP157.3, U94.4
AREF32: JP162.3, U97.4
AREF33: JP167.3, U100.4
AREF34: JP172.3, U103.4
AREF35: JP177.3, U106.4
D0/RXI: JP1.11, U1.16
D0/RXI1: JP6.11, U4.16
D0/RXI2: JP11.11, U7.16
D0/RXI3: JP16.11, U10.16
D0/RXI4: JP21.11, U13.16
D0/RXI5: JP26.11, U16.16
D0/RXI6: JP31.11, U19.16
D0/RXI7: JP36.11, U22.16
D0/RXI8: JP41.11, U25.16
D0/RXI9: JP46.11, U28.16
D0/RXI10: JP51.11, U31.16
D0/RXI11: JP56.11, U34.16
D0/RXI12: JP61.11, U37.16
D0/RXI13: JP66.11, U40.16
D0/RXI14: JP71.11, U43.16
D0/RXI15: JP76.11, U46.16
D0/RXI16: JP81.11, U49.16
D0/RXI17: JP86.11, U52.16
D0/RXI18: JP91.11, U55.16
D0/RXI19: JP96.11, U58.16
D0/RXI20: JP101.11, U61.16
D0/RXI21: JP106.11, U64.16
D0/RXI22: JP111.11, U67.16
D0/RXI23: JP116.11, U70.16
D0/RXI24: JP121.11, U73.16
D0/RXI25: JP126.11, U76.16
D0/RXI26: JP131.11, U79.16
D0/RXI27: JP136.11, U82.16
D0/RXI28: JP141.11, U85.16
D0/RXI29: JP146.11, U88.16
D0/RXI30: JP151.11, U91.16
D0/RXI31: JP156.11, U94.16
D0/RXI32: JP161.11, U97.16
D0/RXI33: JP166.11, U100.16
D0/RXI34: JP171.11, U103.16
D0/RXI35: JP176.11, U106.16
D1: JP6.6, U4.13
D1/TXO: JP1.12, U1.15
D1/TXO1: JP6.12, U4.15
D1/TXO2: JP11.12, U7.15
D1/TXO3: JP16.12, U10.15
D1/TXO4: JP21.12, U13.15
D1/TXO5: JP26.12, U16.15
D1/TXO6: JP31.12, U19.15
D1/TXO7: JP36.12, U22.15
D1/TXO8: JP41.12, U25.15
D1/TXO9: JP46.12, U28.15
D1/TXO10: JP51.12, U31.15
D1/TXO11: JP56.12, U34.15
D1/TXO12: JP61.12, U37.15
D1/TXO13: JP66.12, U40.15
D1/TXO14: JP71.12, U43.15
D1/TXO15: JP76.12, U46.15
D1/TXO16: JP81.12, U49.15
D1/TXO17: JP86.12, U52.15
D1/TXO18: JP91.12, U55.15
D1/TXO19: JP96.12, U58.15
D1/TXO20: JP101.12, U61.15
D1/TXO21: JP106.12, U64.15
D1/TXO22: JP111.12, U67.15
D1/TXO23: JP116.12, U70.15
D1/TXO24: JP121.12, U73.15
D1/TXO25: JP126.12, U76.15
D1/TXO26: JP131.12, U79.15
D1/TXO27: JP136.12, U82.15
D1/TXO28: JP141.12, U85.15
D1/TXO29: JP146.12, U88.15
D1/TXO30: JP151.12, U91.15
D1/TXO31: JP156.12, U94.15
D1/TXO32: JP161.12, U97.15
D1/TXO33: JP166.12, U100.15
D1/TXO34: JP171.12, U103.15
D1/TXO35: JP176.12, U106.15
D2: JP1.8, U1.23
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

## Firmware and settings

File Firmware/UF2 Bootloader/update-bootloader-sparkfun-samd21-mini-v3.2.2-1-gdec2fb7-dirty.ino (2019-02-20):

// Bootloader update sketch. Paste into Arduino IDE and upload to the device
// to update bootloader. It will blink a few times and then start pulsing.
// Your OS will then detect a USB mass storage device.
#include <stdint.h>
const uint8_t bootloader[8192] __attribute__ ((aligned (4))) = {0xd8, 0x2d, 0x00, 0x20, 0x81, 0x02, 0x00, 0x00, 0x7d, 0x02, 0x00, 0x00, 0x7f, 0x02, 0x00, 0x00,
0x00, 0x00, 0x00, 0x00, 0x00, 0x00, 0x00, 0x00, 0x00, 0x00, 0x00, 0x00, 0x00, 0x00, 0x00, 0x00,
0x00, 0x00, 0x00, 0x00, 0x00, 0x00, 0x00, 0x00, 0x00, 0x00, 0x00, 0x00, 0x7d, 0x02, 0x00, 0x00,
0x00, 0x00, 0x00, 0x00, 0x00, 0x00, 0x00, 0x00, 0x7d, 0x02, 0x00, 0x00, 0x75, 0x02, 0x00, 0x00,
0x7d, 0x02, 0x00, 0x00, 0x7d, 0x02, 0x00, 0x00, 0x7d, 0x02, 0x00, 0x00, 0x7d, 0x02, 0x00, 0x00,
0x7d, 0x02, 0x00, 0x00, 0x7d, 0x02, 0x00, 0x00, 0x7d, 0x02, 0x00, 0x00, 0x7d, 0x02, 0x00, 0x00,
0x7d, 0x02, 0x00, 0x00, 0x7d, 0x02, 0x00, 0x00, 0x7d, 0x02, 0x00, 0x00, 0x7d, 0x02, 0x00, 0x00,
0x7d, 0x02, 0x00, 0x00, 0x7d, 0x02, 0x00, 0x00, 0x7d, 0x02, 0x00, 0x00, 0x7d, 0x02, 0x00, 0x00,
0x7d, 0x02, 0x00, 0x00, 0x7d, 0x02, 0x00, 0x00, 0x7d, 0x02, 0x00, 0x00, 0x7d, 0x02, 0x00, 0x00,
0x7d, 0x02, 0x00, 0x00, 0x00, 0x00, 0x00, 0x00, 0x00, 0x00, 0x00, 0x00, 0x7d, 0x02, 0x00, 0x00,
0x7d, 0x02, 0x00, 0x00, 0x7d, 0x02, 0x00, 0x00, 0x7d, 0x02, 0x00, 0x00, 0x7d, 0x02, 0x00, 0x00,
0x00, 0x00, 0x00, 0x00, 0x07, 0x4b, 0x1a, 0x7d, 0xd2, 0x07, 0xfb, 0xd5, 0x20, 0x22, 0xff, 0x32,
0x1a, 0x83, 0x05, 0x4a, 0x40, 0x08, 0xd8, 0x61, 0x1a, 0x80, 0x1a, 0x7d, 0xd2, 0x07, 0xfc, 0xd5,
0x70, 0x47, 0xc0, 0x46, 0x00, 0x40, 0x00, 0x41, 0x02, 0xa5, 0xff, 0xff, 0x10, 0xb5, 0x04, 0x1c,
0x04, 0x4b, 0x9c, 0x42, 0x05, 0xd8, 0x20, 0x1c, 0x01, 0x34, 0xff, 0xf7, 0xe3, 0xff, 0xff, 0x34,
0xf6, 0xe7, 0x10, 0xbd, 0xff, 0xff, 0x03, 0x00, 0x00, 0x23, 0x30, 0xb5, 0x93, 0x42, 0x04, 0xd0,
0x9c, 0x00, 0x0d, 0x59, 0x01, 0x33, 0x05, 0x51, 0xf8, 0xe7, 0x30, 0xbd, 0x70, 0xb5, 0x80, 0x25,
0x0f, 0x4b, 0x5c, 0x68, 0xac, 0x43, 0x5c, 0x60, 0x00, 0x2a, 0x18, 0xd0, 0x14, 0x1e, 0x10, 0x2c,
0x00, 0xd9, 0x10, 0x24, 0x0b, 0x4d, 0x12, 0x1b, 0x1d, 0x80, 0x1d, 0x7d, 0xed, 0x07, 0xfc, 0xd5,
0xa5, 0x00, 0x00, 0x24, 0x0e, 0x59, 0x06, 0x51, 0x04, 0x34, 0xac, 0x42, 0xfa, 0xd1, 0x00, 0x19,
0x09, 0x19, 0x05, 0x4c, 0x1c, 0x80, 0x1c, 0x7d, 0xe4, 0x07, 0xfc, 0xd5, 0xe4, 0xe7, 0x70, 0xbd,
0x00, 0x40, 0x00, 0x41, 0x44, 0xa5, 0xff, 0xff, 0x04, 0xa5, 0xff, 0xff, 0x38, 0xb5, 0x00, 0x23,
0xca, 0x58, 0xc4, 0x58, 0xa2, 0x42, 0x05, 0xd1, 0x80, 0x22, 0x04, 0x33, 0x52, 0x00, 0x93, 0x42,
0xf6, 0xd1, 0x08, 0xe0, 0x0d, 0x1c, 0x04, 0x1c, 0xff, 0xf7, 0x9c, 0xff, 0x20, 0x1c, 0x29, 0x1c,
0x40, 0x22, 0xff, 0xf7, 0xc3, 0xff, 0x38, 0xbd, 0x02, 0x4b, 0x5b, 0x78, 0x5b, 0xb2, 0x00, 0x2b,
0xfa, 0xdb, 0x70, 0x47, 0x00, 0x0c, 0x00, 0x40, 0x02, 0x4b, 0xdb, 0x68, 0xdb, 0x06, 0xfb, 0xd5,
0x70, 0x47, 0xc0, 0x46, 0x00, 0x08, 0x00, 0x40, 0x1e, 0x21, 0xf8, 0xb5, 0x02, 0x26, 0x25, 0x4a,
0x25, 0x4c, 0x53, 0x68, 0x25, 0x4d, 0x8b, 0x43, 0x33, 0x43, 0x53, 0x60, 0xa6, 0x60, 0xff, 0xf7,
0xe3, 0xff, 0x23, 0x4b, 0x63, 0x60, 0xff, 0xf7, 0xdf, 0xff, 0xae, 0x84, 0xff, 0xf7, 0xe4, 0xff,
0x20, 0x4b, 0x1b, 0x68, 0x9b, 0x0e, 0x3f, 0x2b, 0x00, 0xd1, 0x20, 0x3b, 0x00, 0x26, 0x02, 0x27,
0x1d, 0x4a, 0x9b, 0x02, 0x13, 0x43, 0x1d, 0x4a, 0xea, 0x62, 0xab, 0x62, 0xae, 0x84, 0xff, 0xf7,
0xd3, 0xff, 0x1b, 0x4b, 0xab, 0x84, 0xff, 0xf7, 0xcf, 0xff, 0xab, 0x8c, 0x3b, 0x43, 0xab, 0x84,
0xff, 0xf7, 0xca, 0xff, 0x3f, 0x22, 0x63, 0x88, 0x93, 0x43, 0x3b, 0x43, 0x63, 0x80, 0x80, 0x23,
0x62, 0x88, 0xdb, 0x01, 0x13, 0x43, 0x63, 0x80, 0xa6, 0x60, 0xff, 0xf7, 0xb5, 0xff, 0x11, 0x4b,
0x63, 0x60, 0xff, 0xf7, 0xb1, 0xff, 0xc0, 0x20, 0x0f, 0x4a, 0x10, 0x4b, 0x10, 0x49, 0x53, 0x60,
0x0b, 0x6a, 0x00, 0x06, 0x1b, 0x02, 0x1b, 0x0a, 0x03, 0x43, 0x0b, 0x62, 0x07, 0x23, 0x96, 0x60,
0x13, 0x60, 0xf8, 0xbd, 0x00, 0x40, 0x00, 0x41, 0x00, 0x0c, 0x00, 0x40, 0x00, 0x08, 0x00, 0x40,
0x06, 0x00, 0x01, 0x00, 0x24, 0x60, 0x80, 0x00, 0xff, 0x01, 0x00, 0x00, 0x80, 0xbb, 0x0a, 0x1c,
0x24, 0x05, 0x00, 0x00, 0x00, 0x07, 0x03, 0x00, 0x10, 0xe0, 0x00, 0xe0, 0xe7, 0x03, 0x00, 0x00,
0x00, 0xed, 0x00, 0xe0, 0x08, 0xb5, 0x00, 0xf0, 0xf3, 0xf8, 0x08, 0xbd, 0xfe, 0xe7, 0xfe, 0xe7,
0x20, 0x48, 0x21, 0x49, 0x70, 0xb5, 0x00, 0x23, 0x88, 0x42, 0x01, 0xd1, 0x1f, 0x4b, 0x07, 0xe0,
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

};
const uint16_t bootloader_crcs[] = {0x112c ,0x7d55 ,0x7224 ,0x246d ,0x8db2 ,0xed46 ,0xe517 ,0x3cc9};
#define BOOTLOADER_K 8

static uint16_t crcCache[256];

#define CRC16POLY 0x1021

#define FLASH_ROW_SIZE (FLASH_PAGE_SIZE * 4)

uint16_t add_crc(uint8_t ch, unsigned short crc0) {
    if (!crcCache[1]) {
        for (int ptr = 0; ptr < 256; ptr++) {
            uint16_t crc = (int)ptr << 8;
            for (uint16_t cmpt = 0; cmpt < 8; cmpt++) {
                if (crc & 0x8000)
                    crc = crc << 1 ^ CRC16POLY;
                else
                    crc = crc << 1;
            }
            crcCache[ptr] = crc;
        }
    }

    return ((crc0 << 8) ^ crcCache[((crc0 >> 8) ^ ch) & 0xff]) & 0xffff;
}

uint8_t pageBuf[FLASH_ROW_SIZE];

#define NVM_USER_MEMORY ((volatile uint16_t *)NVMCTRL_USER)

static inline void wait_ready(void) {
    while (NVMCTRL->INTFLAG.bit.READY == 0) {
    }
}

void flash_erase_row(uint32_t *dst) {
    wait_ready();
    NVMCTRL->STATUS.reg = NVMCTRL_STATUS_MASK;

    // Execute "ER" Erase Row
    NVMCTRL->ADDR.reg = (uint32_t)dst / 2;
    NVMCTRL->CTRLA.reg = NVMCTRL_CTRLA_CMDEX_KEY | NVMCTRL_CTRLA_CMD_ER;
    wait_ready();
}

void flash_write_words(uint32_t *dst, uint32_t *src, uint32_t n_words) {
    // Set automatic page write
    NVMCTRL->CTRLB.bit.MANW = 0;

    while (n_words > 0) {
        uint32_t len = min(FLASH_PAGE_SIZE >> 2, n_words);
        n_words -= len;

        // Execute "PBC" Page Buffer Clear
        NVMCTRL->CTRLA.reg = NVMCTRL_CTRLA_CMDEX_KEY | NVMCTRL_CTRLA_CMD_PBC;
        wait_ready();

        // make sure there are no other memory writes here
        // otherwise we get lock-ups

        while (len--)
            *dst++ = *src++;

        // Execute "WP" Write Page
        NVMCTRL->CTRLA.reg = NVMCTRL_CTRLA_CMDEX_KEY | NVMCTRL_CTRLA_CMD_WP;
        wait_ready();
    }
}

void flash_write_row(uint32_t *dst, uint32_t *src) {
    flash_erase_row(dst);
    flash_write_words(dst, src, FLASH_ROW_SIZE / 4);
}

#define exec_cmd(cmd)                                                                              \
    do {                                                                                           \
        NVMCTRL->STATUS.reg |= NVMCTRL_STATUS_MASK;                                                \
        NVMCTRL->ADDR.reg = (uint32_t)NVMCTRL_USER / 2;                                            \
        NVMCTRL->CTRLA.reg = NVMCTRL_CTRLA_CMDEX_KEY | cmd;                                        \
        while (NVMCTRL->INTFLAG.bit.READY == 0)                                                    \
            ;                                                                                      \
    } while (0)

void setBootProt(int v) {
    uint32_t fuses[2];

    while (!(NVMCTRL->INTFLAG.reg & NVMCTRL_INTFLAG_READY))
        ;

    fuses[0] = *((uint32_t *)NVMCTRL_AUX0_ADDRESS);
    fuses[1] = *(((uint32_t *)NVMCTRL_AUX0_ADDRESS) + 1);

    uint32_t bootprot = (fuses[0] & NVMCTRL_FUSES_BOOTPROT_Msk) >> NVMCTRL_FUSES_BOOTPROT_Pos;

    if (bootprot == v)
        return;

    fuses[0] = (fuses[0] & ~NVMCTRL_FUSES_BOOTPROT_Msk) | (v << NVMCTRL_FUSES_BOOTPROT_Pos);

    NVMCTRL->CTRLB.reg = NVMCTRL->CTRLB.reg | NVMCTRL_CTRLB_CACHEDIS | NVMCTRL_CTRLB_MANW;

    exec_cmd(NVMCTRL_CTRLA_CMD_EAR);
    exec_cmd(NVMCTRL_CTRLA_CMD_PBC);

    *((uint32_t *)NVMCTRL_AUX0_ADDRESS) = fuses[0];
    *(((uint32_t *)NVMCTRL_AUX0_ADDRESS) + 1) = fuses[1];

    exec_cmd(NVMCTRL_CTRLA_CMD_WAP);

    NVIC_SystemReset();
}

void mydelay(int ms) {
    ms <<= 13;
    while (ms--) {
        asm("nop");
    }
}

void setup() {
    pinMode(LED_BUILTIN, OUTPUT);
    digitalWrite(LED_BUILTIN, HIGH);

    if (8 << NVMCTRL->PARAM.bit.PSZ != FLASH_PAGE_SIZE)
        while (1) {
        }

    __disable_irq();

    setBootProt(7); // 0k

    const uint8_t *ptr = bootloader;
    int i;

    for (i = 0; i < BOOTLOADER_K; ++i) {
        int crc = 0;
        for (int j = 0; j < 1024; ++j) {
            crc = add_crc(*ptr++, crc);
        }
        if (bootloader_crcs[i] != crc) {
            while (1) {
            }
        }
    }

    for (i = 0; i < BOOTLOADER_K * 1024; i += FLASH_ROW_SIZE) {
        memcpy(pageBuf, &bootloader[i], FLASH_ROW_SIZE);
        flash_write_row((uint32_t *)(void *)i, (uint32_t *)(void *)pageBuf);
    }

    // re-base int vector back to bootloader, so that the flash erase below doesn't write over the
    // vectors
    SCB->VTOR = 0;

    // erase first row of this updater app, so the bootloader doesn't start us again
    flash_erase_row((uint32_t *)(void *)(BOOTLOADER_K * 1024));

    for (i = 0; i < 5; ++i) {
        digitalWrite(LED_BUILTIN, HIGH);
        mydelay(100);
        digitalWrite(LED_BUILTIN, LOW);
        mydelay(200);
    }

    setBootProt(2); // 8k

    while (1) {
    }
}

void loop() {}

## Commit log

2015-06-04 Initial commit of hardware.
    [sparkfun-atsamd21g-breakout.brd, sparkfun-atsamd21g-breakout.sch]
2015-06-08 Minor, pre-checklist modifications.
    [sparkfun-atsamd21g-breakout.brd, sparkfun-atsamd21g-breakout.sch]
2015-06-08 Adding PROD_ID's to new parts.
    [sparkfun-atsamd21g-breakout.brd, sparkfun-atsamd21g-breakout.sch]
2015-06-08 Renaming U4 to U3, adding tSilk to pin 11, dimension to .008in.
    [sparkfun-atsamd21g-breakout.brd, sparkfun-atsamd21g-breakout.sch]
2015-06-09 Approving dimension DRC errors near button pads.
    [sparkfun-atsamd21g-breakout.brd]
2015-06-10 created proto panel v01
    [sparkfun-atsamd21g-breakout-ProtoPanel_v01.brd]
2015-09-28 Moving silk. Swapping D4 and D2.
    [sparkfun-atsamd21g-breakout.brd, sparkfun-atsamd21g-breakout.sch]
2015-09-28 Pulling buffer power up to RAW
    [sparkfun-atsamd21g-breakout.brd, sparkfun-atsamd21g-breakout.sch]
2015-09-28 Dropping isolate on internal layers to 10mil
    [sparkfun-atsamd21g-breakout.brd]
2015-09-28 Swapping MIC5205 Regulator out for AP2112K-3.3V
    [sparkfun-atsamd21g-breakout.brd, sparkfun-atsamd21g-breakout.sch]
2015-09-29 Tweaking schematic and layout silk for checklist
    [sparkfun-atsamd21g-breakout.brd, sparkfun-atsamd21g-breakout.sch]
2015-09-30 Sequentiallizing part names
    [sparkfun-atsamd21g-breakout.brd, sparkfun-atsamd21g-breakout.sch]
2015-10-07 created panel v10
    [sparkfun-atsamd21g-breakout-Panel-v10.brd, sparkfun-atsamd21g-breakout-ProtoPanel_v01.brd]
2015-11-12 Renaming hardware files to match product name.
    [sparkfun-samd21-mini-breakout.brd, sparkfun-samd21-mini-breakout.sch]
2015-11-12 Adding v10 schematic.
2015-11-16 Initial commit of SAMD21 Arduino bootloader
2019-02-20 Adds UF2 bootloader and Circuit Python build with a readme
2019-02-21 Updates readme for better clarity, and adds update bootloader binary file for those that prefer that over Arduino sketch

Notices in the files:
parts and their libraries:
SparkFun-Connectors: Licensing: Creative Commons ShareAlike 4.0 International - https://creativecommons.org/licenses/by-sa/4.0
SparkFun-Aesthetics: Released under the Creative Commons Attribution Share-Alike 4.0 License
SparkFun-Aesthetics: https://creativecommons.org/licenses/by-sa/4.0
